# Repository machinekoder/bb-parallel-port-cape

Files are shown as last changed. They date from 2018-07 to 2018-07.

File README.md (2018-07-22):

# BeageBone Parallel Port Cape

This is an open hardware parallel port cape for the BeagleBone.

* [Blog Post about the progress](https://machinekoder.com/working-first-open-source-hardware-parallel-port-cape-beaglebone/)
* [Project at OSH Park](https://oshpark.com/shared_projects/3j2nIZGZ)

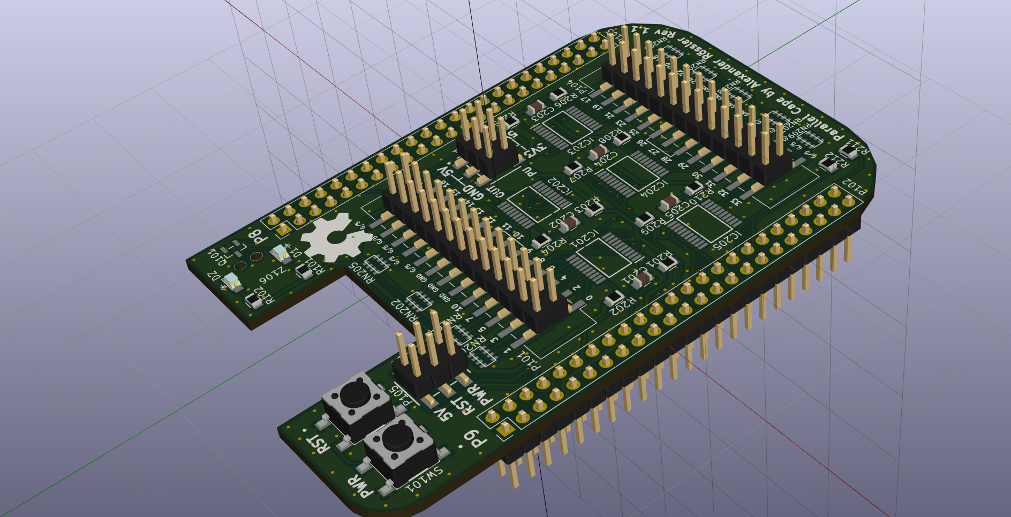
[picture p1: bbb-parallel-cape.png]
3D preview


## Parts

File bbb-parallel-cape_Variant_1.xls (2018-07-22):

Reference | Value | Mfg | PartNo | Count | Variants
SW101 SW102 | SW_Push | C&K | CKN9112CT-ND | 2 | 1
R202 R204 R206 R211 | 200k | Yaego | 311-200KARCT-ND | 4 | 1
D2 | Green | Wurth Electronics Inc. | 732-4983-1-ND | 1 | 1
Z107 Z108 | GENERIC_BLOCK | Sullins | S9000-ND | 2 | 1
R201 R203 R205 R212 | 10k | Yaego | 311-10KARCT-ND | 4 | 1
Z105 | GENERIC_BLOCK | E-Switch | EG2041-ND | 1 | 1
D1 | Yellow | Wurth Electronics Inc. | 732-4987-1-ND | 1 | 1
C201 C202 C203 | 0.1u | Samsung Electro-Mechanics | 1276-1007-1-ND | 3 | 1
IC201 IC202 IC203 | GTL2003PW | NXP USA Inc. | 568-4232-5-ND | 3 | 1
P105 JP101 | Jumper_NC_Dual_Double_Header | Harwin Inc. | 952-1922-ND | 2 | 1
Q101 | 2N7002K | ON Semiconductor | 2N7002KT1GOSCT-ND | 1 | 1
Z106 | Light_Pipe_2_LED | Dialight | 350-3399-ND | 1 | 1
P101 | IDC26 | CNC Tech | 1175-1625-ND | 1 | 1
R102 R101 | 330 | Yaego | 311-330ARCT-ND | 2 | 1
RN201 RN204 RN202 RN205 RN203 | 10k | Bourns Inc. | CAT16-103J4LFCT-ND | 5 | 1
P102 P103 | BeagleBone_Black_Header | Sullins | S2211EC-23-ND | 2 | 1
 |  |  | Different parts | 16
 |  |  | Total parts | 35

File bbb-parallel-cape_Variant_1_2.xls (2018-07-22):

Reference | Value | Mfg | PartNo | Count | Variants | Count 3 | Count 5
SW101 SW102 | SW_Push | C&K | CKN9112CT-ND | 2 | 1 | 6 | 10
R202 R204 R206 R208 R210 R211 | 200k | Yaego | 311-200KARCT-ND | 6 | 1 2 | 18 | 30
D2 | Green | Wurth Electronics Inc. | 732-4983-1-ND | 1 | 1 | 3 | 5
Z107 Z108 | GENERIC_BLOCK | Sullins | S9000-ND | 2 | 1 | 6 | 10
R201 R203 R205 R207 R209 R212 | 10k | Yaego | 311-10KARCT-ND | 6 | 1 2 | 18 | 30
Z105 | GENERIC_BLOCK | E-Switch | EG2041-ND | 1 | 1 | 3 | 5
D1 | Yellow | Wurth Electronics Inc. | 732-4987-1-ND | 1 | 1 | 3 | 5
C201 C202 C203 C204 C205 | 0.1u | Samsung Electro-Mechanics | 1276-1007-1-ND | 5 | 1 2 | 15 | 25
IC201 IC202 IC203 IC204 IC205 | GTL2003PW | NXP USA Inc. | 568-4232-5-ND | 5 | 1 2 | 15 | 25
P105 JP101 | Jumper_NC_Dual_Double_Header | Harwin Inc. | 952-1922-ND | 2 | 1 | 6 | 10
Q101 | 2N7002K | ON Semiconductor | 2N7002KT1GOSCT-ND | 1 | 1 | 3 | 5
Z106 | Light_Pipe_2_LED | Dialight | 350-3399-ND | 1 | 1 | 3 | 5
P101 P104 | IDC26 | CNC Tech | 1175-1625-ND | 2 | 1 2 | 6 | 10
R102 R101 | 330 | Yaego | 311-330ARCT-ND | 2 | 1 | 6 | 10
RN201 RN204 RN202 RN205 RN203 RN206 RN208 RN207 RN209 | 10k | Bourns Inc. | CAT16-103J4LFCT-ND | 9 | 1 2 | 27 | 45
P102 P103 | BeagleBone_Black_Header | Sullins | S2211EC-23-ND | 2 | 1 | 6 | 10
 |  |  | Different parts | 16
 |  |  | Total parts | 48

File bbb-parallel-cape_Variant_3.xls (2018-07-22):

Reference | Value | Mfg | PartNo | Count | Variants | Count 3 | Count 5
Z102 Z104 | GENERIC_BLOCK | 3M | MC26G-5-ND | 2 | 3 | 6 | 10
Z101 Z103 | GENERIC_BLOCK | CNC Tech | 1175-1444-ND | 2 | 3 | 6 | 10
J102 | DB25M | CNC Tech | 1175-1815-ND | 1 | 3 | 3 | 5
J101 | DB25F | CNC Tech | 410F0-25-1-00 | 1 | 3 | 3 | 5
 |  |  | Different parts | 4
 |  |  | Total parts | 6

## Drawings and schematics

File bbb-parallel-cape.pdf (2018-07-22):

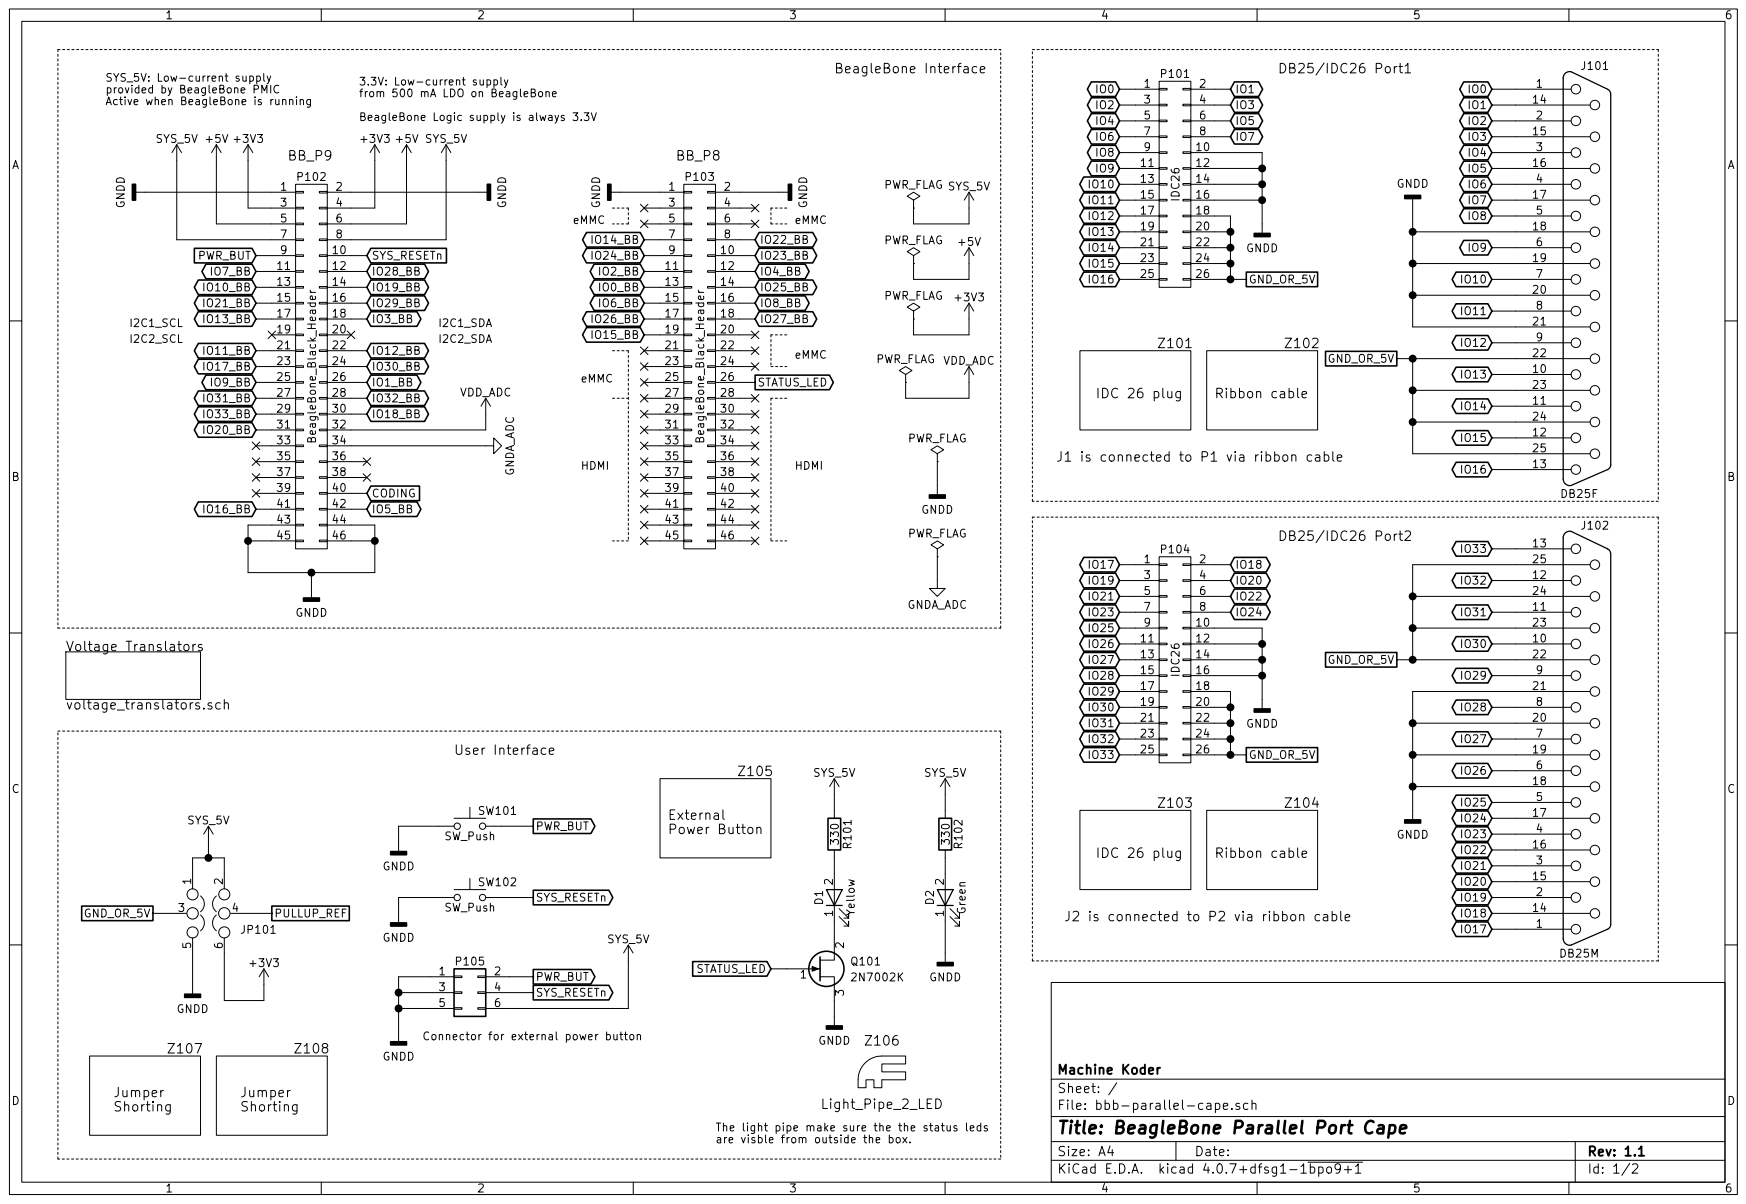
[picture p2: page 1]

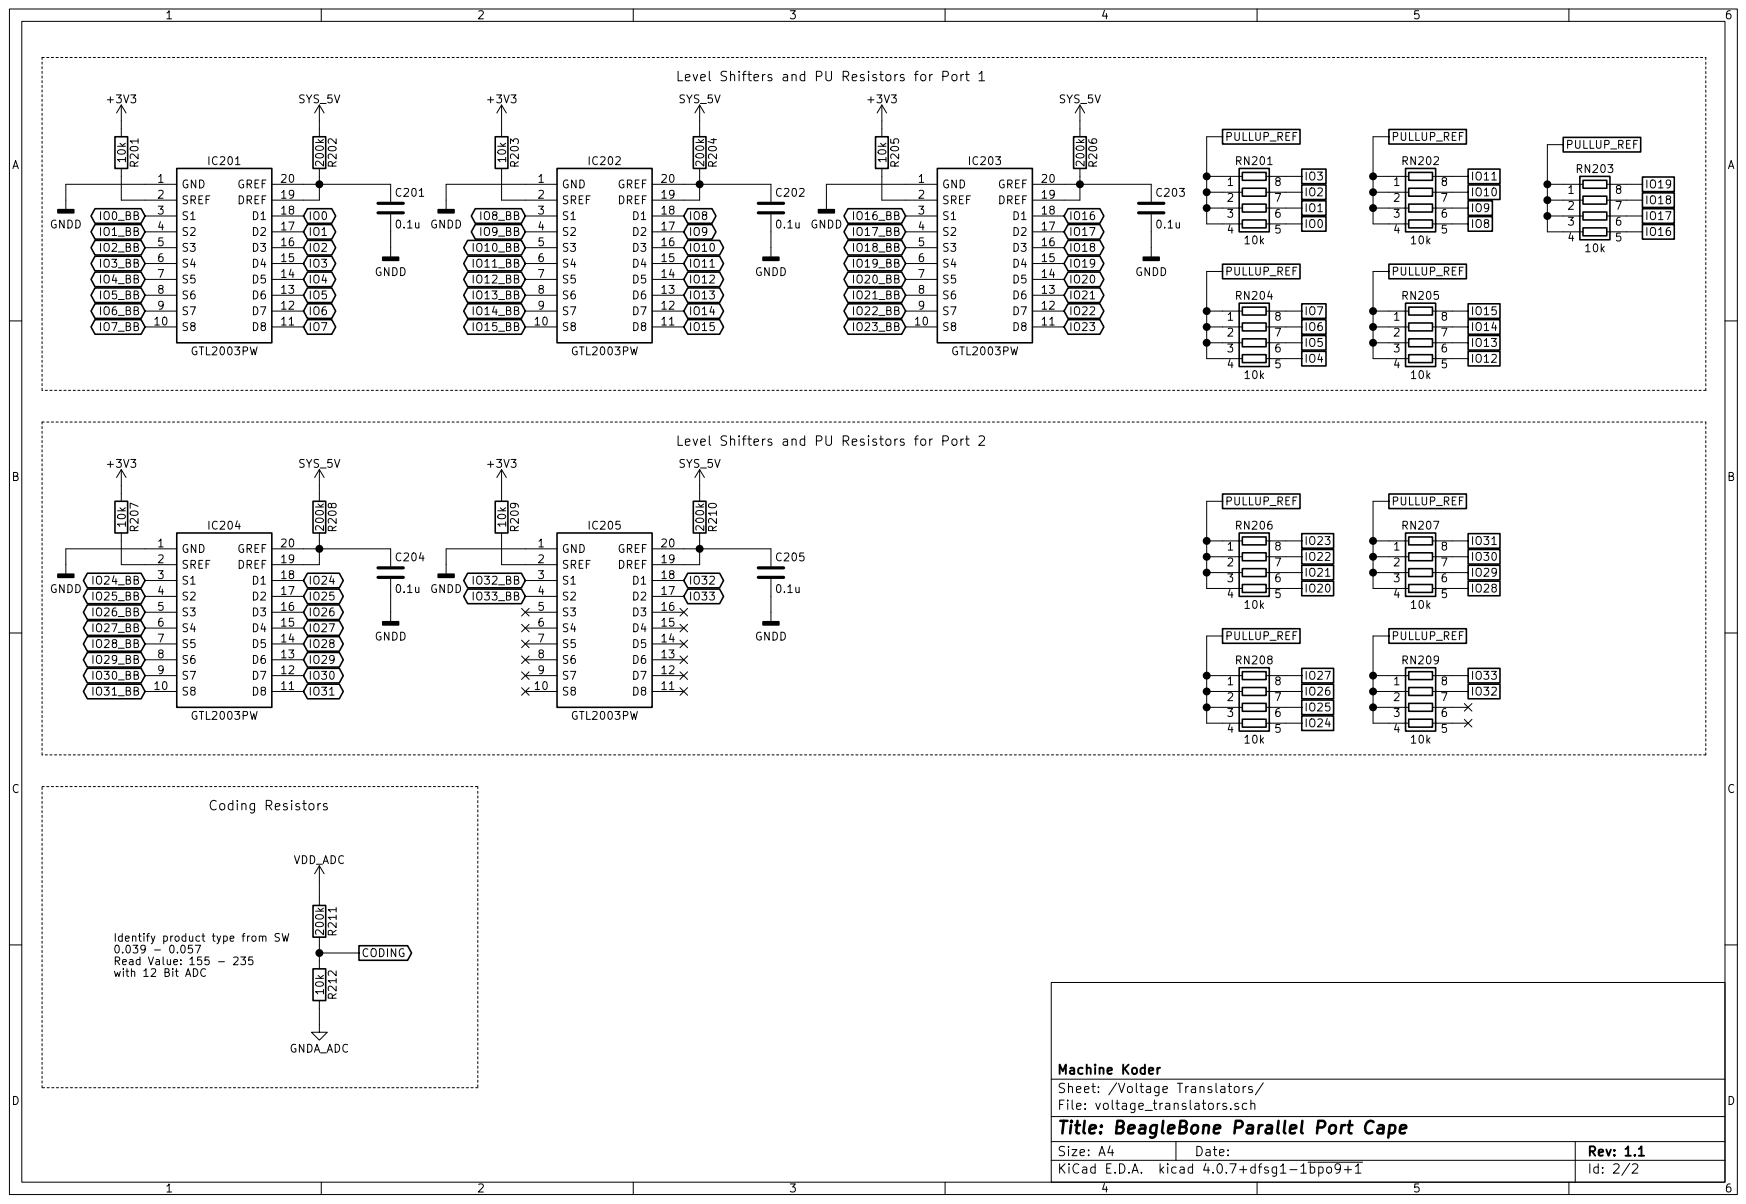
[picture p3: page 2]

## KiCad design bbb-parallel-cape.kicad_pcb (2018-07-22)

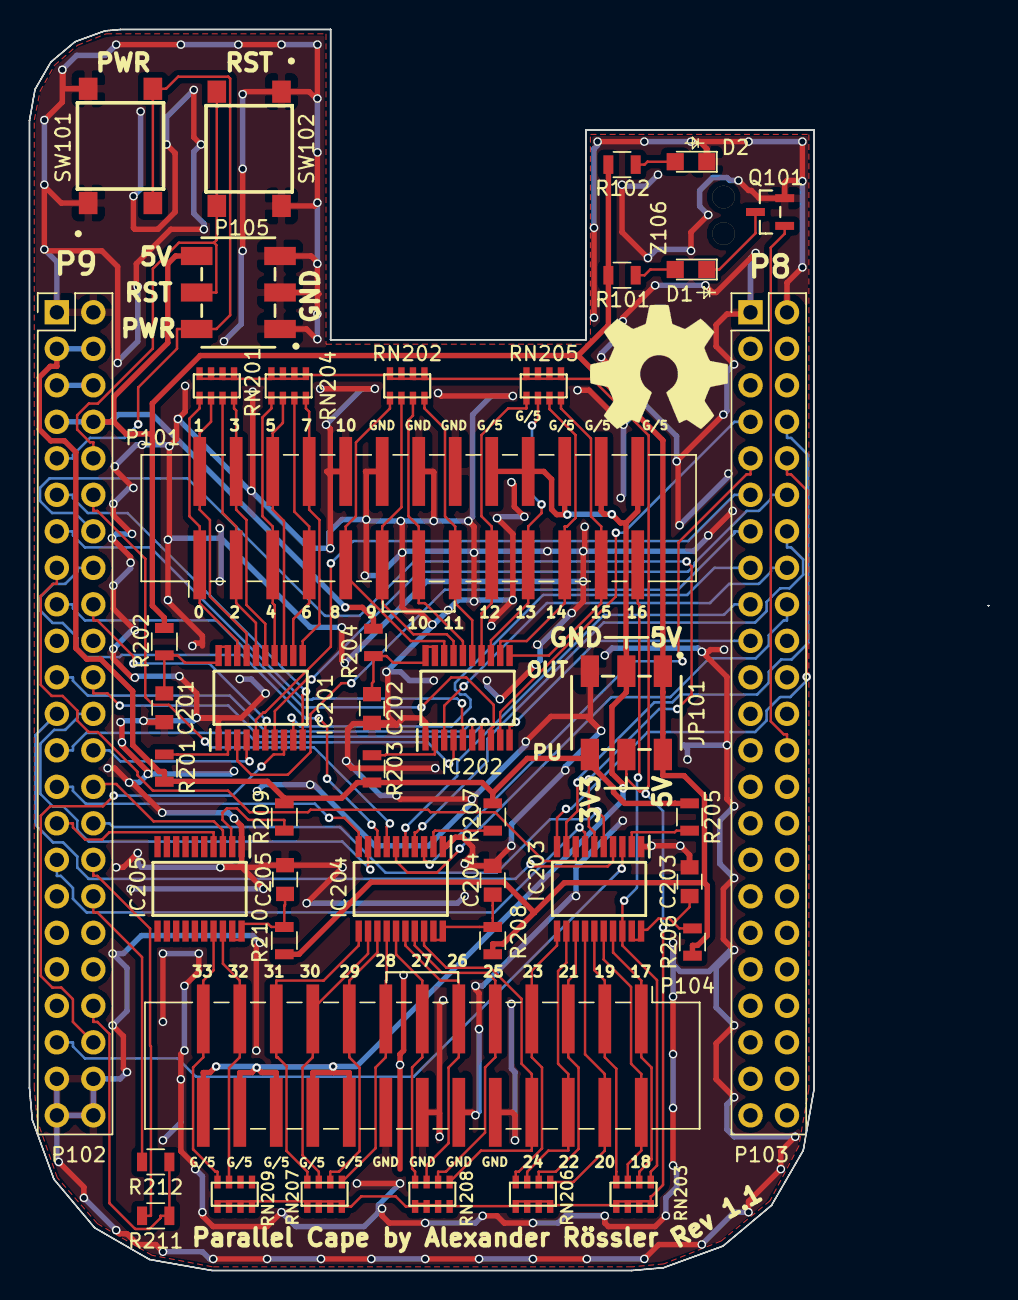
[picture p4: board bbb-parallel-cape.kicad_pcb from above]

Board: 2 copper layers, 54.6 x 86.4 mm, 45 parts (0 on the bottom side), 93 nets.

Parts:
C201, C202, C203, C204, C205: 0.1u; C_0805
D1: Yellow; LED_0805
D2: Green; LED_0805
IC201, IC202, IC203, IC204, IC205: GTL2003PW; SOP65P640X110-20N
JP101: Jumper_NC_Dual_Double_Header; M20-8760342
P101, P104: IDC26
P102, P103: BeagleBone_Black_Header; Pin_Header_Straight_2x23_Pitch2.54mm
P105: Conn_02x03_Odd_Even; M20-8760342
Q101: 2N7002K; SOT95P240X105-3N
R101, R102: 330; R_0805
R201, R203, R205, R207, R209, R212: 10k; R_0805
R202, R204, R206, R208, R210, R211: 200k; R_0805
RN201, RN202, RN203, RN204, RN205, RN206, RN207, RN208, RN209: 10k; CAT_CAY16
SW101, SW102: SW_Push; PTS645_SMT
Z106: Light_Pipe_2_LED; 515-1114F_2

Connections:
+3V3: JP101.6, P102.3, P102.4, R201.1, R203.1, R205.1, R207.1, R209.1
+5V: P102.5, P102.6
CODING: P102.40, R211.2, R212.1
GNDA_ADC: P102.34, R212.2
GNDD: C201.2, C202.2, C203.2, C204.2, C205.2, D2.1, IC201.1, IC202.1, IC203.1, IC204.1, IC205.1, JP101.5, P101.10, P101.12, P101.14, P101.16, P102.1, P102.2, P102.43, P102.44, P102.45, P102.46, P103.1, P103.2, P104.10, P104.12, P104.14, P104.16, P105.1, P105.3, P105.5, Q101.3, SW101.1, SW102.1
GND_OR_5V: JP101.3, P101.18, P101.20, P101.22, P101.24, P101.26, P104.18, P104.20, P104.22, P104.24, P104.26
IO0: IC201.18, P101.1, RN201.5
IO0_BB: IC201.3, P103.13
IO1: IC201.17, P101.2, RN201.6
IO1_BB: IC201.4, P102.26
IO2: IC201.16, P101.3, RN201.7
IO2_BB: IC201.5, P103.11
IO3: IC201.15, P101.4, RN201.8
IO3_BB: IC201.6, P102.18
IO4: IC201.14, P101.5, RN204.5
IO4_BB: IC201.7, P103.12
IO5: IC201.13, P101.6, RN204.6
IO5_BB: IC201.8, P102.42
IO6: IC201.12, P101.7, RN204.7
IO6_BB: IC201.9, P103.15
IO7: IC201.11, P101.8, RN204.8
IO7_BB: IC201.10, P102.11
IO8: IC202.18, P101.9, RN202.5
IO8_BB: IC202.3, P103.16
IO9: IC202.17, P101.11, RN202.6
IO9_BB: IC202.4, P102.25
IO10: IC202.16, P101.13, RN202.7
IO10_BB: IC202.5, P102.13
IO11: IC202.15, P101.15, RN202.8
IO11_BB: IC202.6, P102.21
IO12: IC202.14, P101.17, RN205.5
IO12_BB: IC202.7, P102.22
IO13: IC202.13, P101.19, RN205.6
IO13_BB: IC202.8, P102.17
IO14: IC202.12, P101.21, RN205.7
IO14_BB: IC202.9, P103.7
IO15: IC202.11, P101.23, RN205.8
IO15_BB: IC202.10, P103.19
IO16: IC203.18, P101.25, RN203.5
IO16_BB: IC203.3, P102.41
IO17: IC203.17, P104.1, RN203.6
IO17_BB: IC203.4, P102.23
IO18: IC203.16, P104.2, RN203.7
IO18_BB: IC203.5, P102.30
IO19: IC203.15, P104.3, RN203.8
IO19_BB: IC203.6, P102.14
IO20: IC203.14, P104.4, RN206.5
IO20_BB: IC203.7, P102.31
IO21: IC203.13, P104.5, RN206.6
IO21_BB: IC203.8, P102.15
IO22: IC203.12, P104.6, RN206.7
IO22_BB: IC203.9, P103.8
IO23: IC203.11, P104.7, RN206.8
IO23_BB: IC203.10, P103.10
IO24: IC204.18, P104.8, RN208.5
IO24_BB: IC204.3, P103.9
IO25: IC204.17, P104.9, RN208.6
IO25_BB: IC204.4, P103.14
IO26: IC204.16, P104.11, RN208.7
IO26_BB: IC204.5, P103.17
IO27: IC204.15, P104.13, RN208.8
IO27_BB: IC204.6, P103.18
IO28: IC204.14, P104.15, RN207.5
IO28_BB: IC204.7, P102.12
IO29: IC204.13, P104.17, RN207.6
IO29_BB: IC204.8, P102.16
IO30: IC204.12, P104.19, RN207.7
IO30_BB: IC204.9, P102.24
IO31: IC204.11, P104.21, RN207.8
IO31_BB: IC204.10, P102.27
IO32: IC205.18, P104.23, RN209.7
IO32_BB: IC205.3, P102.28
IO33: IC205.17, P104.25, RN209.8
IO33_BB: IC205.4, P102.29
unnamed: C201.1, IC201.19, IC201.20, R202.2
unnamed: C202.1, IC202.19, IC202.20, R204.2
unnamed: C203.1, IC203.19, IC203.20, R206.2
unnamed: C204.1, IC204.19, IC204.20, R208.2
unnamed: C205.1, IC205.19, IC205.20, R210.2
unnamed: D1.1, Q101.2
unnamed: D1.2, R101.2
unnamed: D2.2, R102.2
unnamed: IC201.2, R201.2
unnamed: IC202.2, R203.2
unnamed: IC203.2, R205.2
unnamed: IC204.2, R207.2
unnamed: IC205.2, R209.2
PULLUP_REF: JP101.4, RN201.1, RN201.2, RN201.3, RN201.4, RN202.1, RN202.2, RN202.3, RN202.4, RN203.1, RN203.2, RN203.3, RN203.4, RN204.1, RN204.2, RN204.3, RN204.4, RN205.1, RN205.2, RN205.3, RN205.4, RN206.1, RN206.2, RN206.3, RN206.4, RN207.1, RN207.2, RN207.3, RN207.4, RN208.1, RN208.2, RN208.3, RN208.4, RN209.1, RN209.2, RN209.3, RN209.4
PWR_BUT: P102.9, P105.2, SW101.2
STATUS_LED: P103.26, Q101.1
SYS_5V: JP101.1, JP101.2, P102.7, P102.8, P105.6, R101.1, R102.1, R202.1, R204.1, R206.1, R208.1, R210.1
SYS_RESETn: P102.10, P105.4, SW102.2
VDD_ADC: P102.32, R211.1

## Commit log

2018-01-13 before placement
    [bbb-parallel-cape.csv, bbb-parallel-cape.kicad_pcb, bbb-parallel-cape.sch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]
2018-01-13 before edge cut
    [bbb-parallel-cape.kicad_pcb]
2018-03-04 revision1 files
    [bbb-parallel-cape.csv, bbb-parallel-cape.kicad_pcb, bbb-parallel-cape.sch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]
2018-03-18 revision 1.1 before via stitching
    [bbb-parallel-cape.dsn, bbb-parallel-cape.kicad_pcb, bbb-parallel-cape.sch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]
2018-03-22 completing Rev 1.1
    [bbb-parallel-cape.kicad_pcb]
2018-07-22 updating project
    [bbb-parallel-cape.csv, bbb-parallel-cape.kicad_pcb, bbb-parallel-cape.sch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]
